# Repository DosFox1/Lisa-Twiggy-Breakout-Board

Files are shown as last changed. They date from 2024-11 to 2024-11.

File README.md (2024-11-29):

# Lisa-Twiggy-Breakout-Board
A fork of Roland Juno's original Lisa breakout board - now with Twiggy!

top
bottom

# So... What is it? 
This is a variant of RolandJunos original Lisa breakout board (https://github.com/RolandJuno/Lisa_Breakout), that includes an additional connector for the Lisa LITE. 
Adding the Lisa LITE connector will allow for 400K Floppy Drives to be connected to a Lisa.
This is because the Lisa LITE generates a PWM signal for the main drive motor in the 400K floppy drive. 
In a Macintosh, this PWM signal is generated by the ASG and audio interface! (I mean, I guess it's all PWM signals).

However, 800K drives and Floppy Emu generate their own PWM signal - so that pin is usually left disconnected. 
As a result, you can use a passive adapter for those drives.

Note, in the surprising event that you have an actual Twiggy Drive, please note this probably will not work.
This is because to two signals (sense and read) are tied together for the 800K drive. I felt a bit lazy and didn't add a way to keep these separate. 
If you have a Twiggy, cut and strap I guess? 

# Engineers Notes
The BOM remains the same as the original breakout board, except for the addition of a 26 pin shrouded connector for the Twiggy pinout.

**IMPORTANT:**

Do NOT connect a Twiggy/Lisa LITE at the same time as a Sony Drive. They share the same enable lines, and bad stuff (TM) is likely to happen. 
So don't do that. 

**Errata and other notes:**

* I've cleaned up some of the tracks and added thermal relief for soldering. 
* The errata for the 7905 footprint has been fixed (and added some silk to make sure the polarity is right!).
* AGND is also now connected to normal DGND, so no jumper is needed.
* Mounting holes have now been added (three in total), which are positioned in a line on the board. This will help with case building.
* To help with case building, the included SVGs are 1:1 scale to the actual board, meaning they can be imported into your favourite CAD program to help build a case around it.

**NOTE - This is Entirely Untested. Proceed With Caution**

It's best practise to power thsi adapter board with a bare (I.E, no IC's present) motherboard for intial testing.

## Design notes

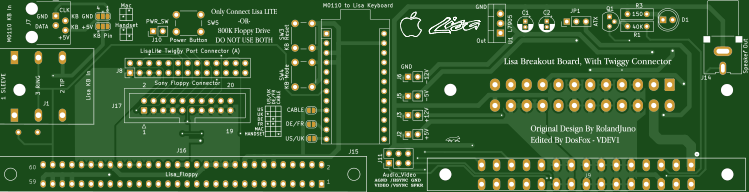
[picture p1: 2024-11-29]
Images/top.png

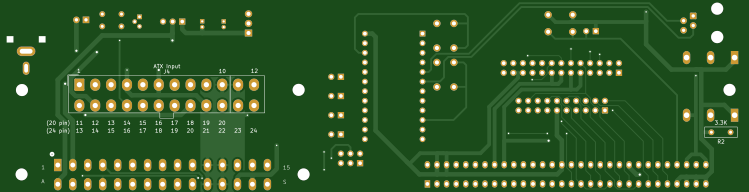
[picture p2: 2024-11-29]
Images/bottom.png

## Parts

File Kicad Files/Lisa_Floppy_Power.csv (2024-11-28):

# | Reference | Qty | Value | Footprint | DNP
1 | C1, C2 | 2 | 0.1uf | Capacitor_THT:CP_Radial_D4.0mm_P1.50mm
2 | D1 | 1 | LED | LED_THT:LED_D5.0mm
3 | J1 | 1 | Keyboard | my_libs:0.25IN_STEREO_HEADPHONE_JACK
4 | J2 | 1 | +5V | Connector_PinHeader_2.54mm:PinHeader_1x02_P2.54mm_Vertical
5 | J3 | 1 | +12V | Connector_PinHeader_2.54mm:PinHeader_1x02_P2.54mm_Vertical
6 | J4 | 1 | ATX-24 | Connector_Molex:Molex_Mini-Fit_Jr_5566-24A_2x12_P4.20mm_Vertical
7 | J5 | 1 | -5V | Connector_PinHeader_2.54mm:PinHeader_1x02_P2.54mm_Vertical
8 | J6 | 1 | -12V | Connector_PinHeader_2.54mm:PinHeader_1x02_P2.54mm_Vertical
9 | J7 | 1 | Mac_Plus_RJ9-4P4C | Connector_RJ:RJ9_Evercom_5301-440xxx_Horizontal
10 | J9 | 1 | Lisa_Power_Video_Sound_Edge | my_libs:Lisa Motherboard Power Edge
11 | J10 | 1 | Power_Switch_External | Connector_PinHeader_2.54mm:PinHeader_1x02_P2.54mm_Vertical
12 | J11 | 1 | Audio_Video | Connector_PinHeader_2.54mm:PinHeader_2x03_P2.54mm_Vertical
13 | J14 | 1 | Speaker_Out | my_libs:CUI_RCJ-047
14 | J15 | 1 | Arduino_Pro_Micro_5V_16MHz | Arduino:Sparkfun_Pro_Micro
15 | J16 | 1 | Lisa_Floppy | my_libs:1-5530841-8_TE_CONN_60_DUAL_EDGE
16 | J17 | 1 | Floppy_A | Connector_IDC:IDC-Header_2x10_P2.54mm_Vertical
17 | JP1 | 1 | -5V_Selector | Connector_PinHeader_2.54mm:PinHeader_1x03_P2.54mm_Vertical
18 | JP2 | 1 | KB +5V Pin | Jumper:SolderJumper-3_P1.3mm_Bridged12_RoundedPad1.0x1.5mm
19 | JP3 | 1 | KB GND Pin | Jumper:SolderJumper-3_P1.3mm_Bridged12_RoundedPad1.0x1.5mm
20 | JP4 | 1 | US/UK | Jumper:SolderJumper-2_P1.3mm_Open_RoundedPad1.0x1.5mm
21 | JP5 | 1 | DE/FR | Jumper:SolderJumper-2_P1.3mm_Open_RoundedPad1.0x1.5mm
22 | JP6 | 1 | CABLE | Jumper:SolderJumper-2_P1.3mm_Open_RoundedPad1.0x1.5mm
23 | Q1 | 1 | 2N4401BU | Package_TO_SOT_THT:TO-92
24 | R1 | 1 | 40K | Resistor_THT:R_Box_L8.4mm_W2.5mm_P5.08mm
25 | R2 | 1 | 3.3K | Resistor_THT:R_Box_L8.4mm_W2.5mm_P5.08mm
26 | R3 | 1 | 150 | Resistor_THT:R_Box_L8.4mm_W2.5mm_P5.08mm
27 | SW3 | 1 | Keyboard_Reset | Button_Switch_THT:SW_PUSH_6mm
28 | SW4 | 1 | Keyboard_Mode | Button_Switch_THT:SW_PUSH_6mm
29 | SW5 | 1 | Power_Button | Button_Switch_THT:SW_PUSH_6mm
30 | U1 | 1 | L7905 | Package_TO_SOT_THT:TO-220-3_Vertical

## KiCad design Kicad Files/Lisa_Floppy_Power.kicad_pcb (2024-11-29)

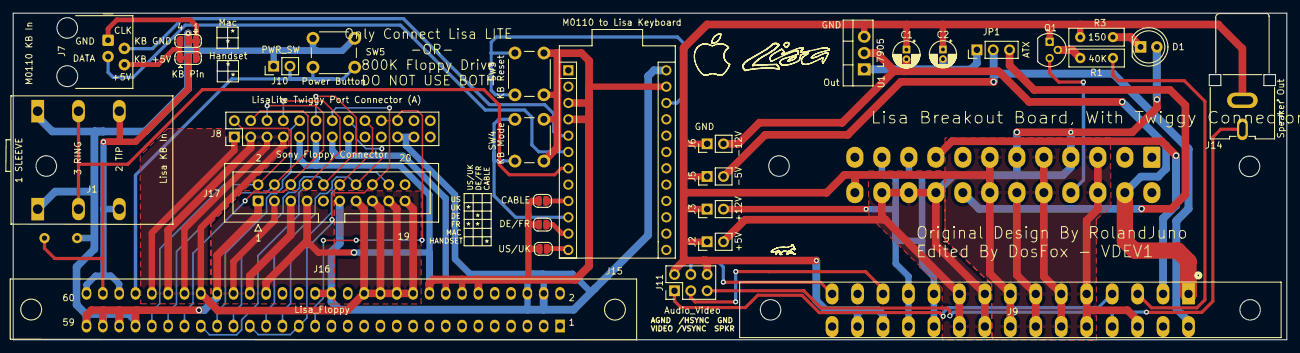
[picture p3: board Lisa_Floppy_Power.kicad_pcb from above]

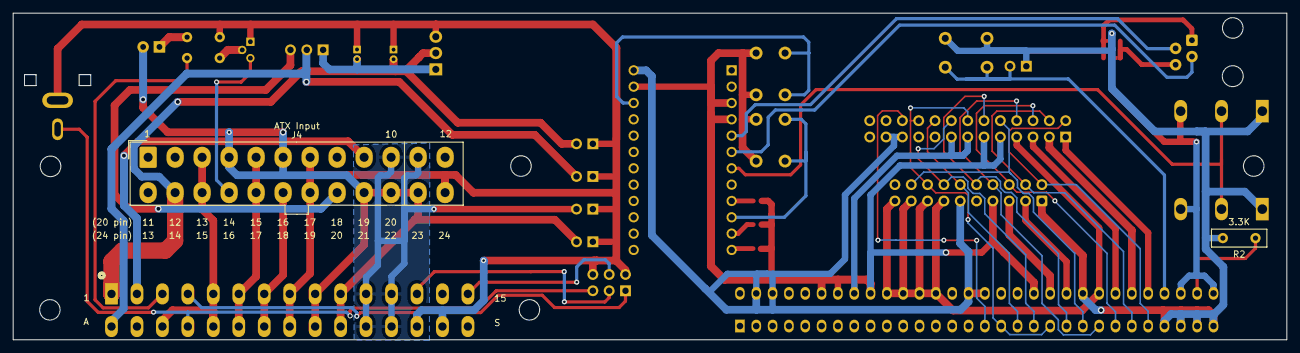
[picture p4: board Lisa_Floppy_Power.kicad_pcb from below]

Board: 2 copper layers, 198.1 x 50.8 mm, 32 parts (2 on the bottom side), 41 nets.

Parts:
C1, C2: 0.1uf; CP_Radial_D4.0mm_P1.50mm
D1: LED; LED_D5.0mm
J1: Lisa KB In; 0.25IN_STEREO_HEADPHONE_JACK
J2: +5V; PinHeader_1x02_P2.54mm_Vertical
J3: +12V; PinHeader_1x02_P2.54mm_Vertical
J4: ATX-24; Molex_Mini-Fit_Jr_5566-24A_2x12_P4.20mm_Vertical
J5: -5V; PinHeader_1x02_P2.54mm_Vertical
J6: -12V; PinHeader_1x02_P2.54mm_Vertical
J7: Mac_Plus_RJ9-4P4C; RJ9_Evercom_5301-440xxx_Horizontal
J8: LisaLite Twiggy Port Connector (A); PinHeader_2x13_P2.54mm_Vertical
J9: Lisa_Power_Video_Sound_Edge; Lisa Motherboard Power Edge
J10: PWR_SW; PinHeader_1x02_P2.54mm_Vertical
J11: Audio_Video; PinHeader_2x03_P2.54mm_Vertical
J14: Speaker Out; CUI_RCJ-047
J15: Arduino_Pro_Micro_5V_16MHz; Sparkfun_Pro_Micro
J16: Lisa_Floppy; 1-5530841-8_TE_CONN_60_DUAL_EDGE
J17: Sony Floppy Connector; IDC-Header_2x10_P2.54mm_Vertical
JP1: -5V_Selector; PinHeader_1x03_P2.54mm_Vertical
JP2: KB +5V; SolderJumper-3_P1.3mm_Bridged12_RoundedPad1.0x1.5mm
JP3: KB GND; SolderJumper-3_P1.3mm_Bridged12_RoundedPad1.0x1.5mm
JP4: US/UK; SolderJumper-2_P1.3mm_Open_RoundedPad1.0x1.5mm
JP5: DE/FR; SolderJumper-2_P1.3mm_Open_RoundedPad1.0x1.5mm
JP6: CABLE; SolderJumper-2_P1.3mm_Open_RoundedPad1.0x1.5mm
Q1: 2N4401BU; TO-92
R1: 40K; R_Box_L8.4mm_W2.5mm_P5.08mm
R2: 3.3K; R_Box_L8.4mm_W2.5mm_P5.08mm
R3: 150; R_Box_L8.4mm_W2.5mm_P5.08mm
SW3: KB Reset; SW_PUSH_6mm
SW4: KB Mode; SW_PUSH_6mm
SW5: Power Button; SW_PUSH_6mm
U1: L7905; TO-220-3_Vertical

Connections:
+5V: D1.2 (A), J2.2, J4.4 (+5V), J4.6 (+5V), J4.21 (+5V), J4.22 (+5V), J4.23 (+5V), J9.9, J9.10, J9.K, J9.L
+5VSB: J4.9 (+5VSB), J9.2
+5V_L: J8.21 (+5V), J8.23 (+5V), J15.24 (RAW), J16.4, J16.6, J16.30, J16.32, J17.11
+5V_L1: J1.2 (T), J16.56, J16.60, JP2.2 (C)
+12V-L: J8.1 (+12V), J8.3 (+12V), J8.5 (+12V), J8.7 (+12V), J16.20, J16.22, J16.24, J16.26, J16.46, J16.48, J16.50, J16.52, J17.13, J17.15, J17.17, J17.19
+12V-R: J3.2, J4.10 (+12V), J4.11 (+12V), J9.11, J9.12, J9.M, J9.N
-5V: J5.2, J9.A, JP1.2 (C)
-5V_7905: C2.2, JP1.1 (A), U1.1 (GND)
-5V_ATX: J4.20 (-5V), JP1.3 (B)
-12V: C1.2, J4.14 (-12V), J6.2, J9.1, U1.2 (VI)
CABLE: J15.9 (~D6/A7), JP6.2 (B)
DE/FR: J15.11 (D8/A8), JP5.2 (B)
GND-L: J1.1 (S), J8.9 (GND), J8.11 (GND), J8.13 (GND), J8.15 (GND), J10.1, J15.3 (GND), J15.4 (GND), J15.23 (GND), J16.12, J16.14, J16.16, J16.18, J16.38, J16.40, J16.42, J16.44, J16.53, J16.55, J16.57, J16.59, J17.1, J17.3, J17.5, J17.7, JP3.2 (C), JP4.1 (A), JP5.1 (A), JP6.1 (A), R2.2, SW3.1, SW4.1, SW5.1
GND-R: C1.1, C2.1, J2.1, J3.1, J4.3 (GND), J4.5 (GND), J4.7 (GND), J4.15 (GND), J4.17 (GND), J4.18 (GND), J4.19 (GND), J4.24 (GND), J5.1, J6.1, J9.5, J9.6, J9.7, J9.8, J9.C, J9.E, J9.F, J9.H, J9.J, J9.P, J9.R, J11.2, J11.6, J14.1, Q1.1 (E), R3.1, U1.3 (VO)
GND/VCC: J7.4, JP2.1 (A), JP3.3 (B)
HDS-A: J8.18 (HEADSEL), J16.35, J17.12
KBD: J1.3 (R), J15.7 (D4/A6), J16.58, R2.1
KBD_RESET: J15.22 (RST), SW3.2
M0110_CLK: J7.3, J15.6 (~D3)
M0110_DATA: J7.2, J15.5 (D2)
MOD: J15.10 (D7), SW4.2
MOTRCLK: J8.22 (MOTRCLK), J16.31
unnamed: D1.1 (K), R3.2
unnamed: Q1.2 (B), R1.2
ON/OFF: J9.3, R1.1
PH0-A: J8.2 (PH0), J16.51, J17.2
PH1-A: J8.4 (PH1), J16.49, J17.4
PH2-A: J8.6 (PH2), J16.47, J17.6
PH3-A: J8.8 (PH3), J16.45, J17.8
PS_ON: J4.16 (PS_ON#), Q1.3 (C)
PWRSW: J10.2, J16.54, SW5.2
RDA-A: J8.14 (RD), J8.20 (SENSE), J16.33, J16.39, J17.16
SPKR: J9.D, J11.5, J14.2
US/UK: J15.12 (~D9/A9), JP4.2 (B)
VCC/GND: J7.1, JP2.3 (B), JP3.1 (A)
VIDEO: J9.4, J11.1
WRD-A: J8.10 (WR), J16.43, J17.18
/DR1-A: J8.16 (/DRVSEL), J16.37, J17.14
/HSYNC: J9.15, J11.4
/VSYNC: J9.13, J11.3
/WRQ-A: J8.12 (/WREQ), J16.41, J17.10

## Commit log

2024-11-28 Add files via upload
    Added initial files
    [Lisa_Floppy_Power-B_Cu.gbr, Lisa_Floppy_Power-B_Mask.gbr, Lisa_Floppy_Power-B_Silkscreen.gbr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]
2024-11-29 Add files via upload
    Fixed 7905 pinout
    [Lisa_Floppy_Power-B_Cu.gbr, Lisa_Floppy_Power-B_Mask.gbr, Lisa_Floppy_Power-B_Silkscreen.gbr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]
2024-11-29 Add files via upload
    KiCad files with updated 7905 footprint
    [Lisa_Floppy_Power.kicad_pcb]
